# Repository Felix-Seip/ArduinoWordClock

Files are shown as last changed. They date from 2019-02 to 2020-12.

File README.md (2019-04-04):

# ArduinoWordClock
A code repository for an arduino word clock

This project was inspired by the QlockTwo word clock, which is uses the same basic code logic.
Currently, the only language that is supported with this repository is German. 
This is due to the layout of the LED matrix and the hardcoded position of the LEDs in the code.

However, this code can be used a basis of any word clock with an 11 x 11 LED matrix.

The main file for this clock is the .ino file, which is the main file that runs on the Arduino.
The other files, define a class that represent a word on the clock. 
These words include the words for the hours and minutes. 
The other words such as "vor" and "nach" are hard coded.

## Part List
This project uses a few different components in order to show the time in the LED matrix.
The following list is the part list required to recreate this word clock:
- 121 LEDs. The LEDs that should be used are LED strips. Each strip contains 11 LEDs. Since there are 11 rows, 121 LEDs are required
- DS1307 RTC. The RTC is used to control the LEDs and show the words on the clock
- DS18B20 Temperature Sensor. The sensor is used to display the temperature of the room that the clock is in
- GL5528 Photoresistor. The photoresistor is used to set the brightness of the LEDs depending on how bright it is in the room
- 1 x 10k Ohm Resistor
- 1 x 4.7k Ohm Resistor
- Arduino UNO or any other microcontroller with an ATMega328P chip
- HM-10 Bluetooth 4.0 Chip, available from DSD Tech on amazon.de

## LED Matrix Layout
The LED matrix that is used in this project is an 11 x 11 matrix. 
The LEDs are set up as follows:
11 LED strips. Each strip is one row for the matrix. 
Each LED strip contains 11 LEDs, thus the LED matrix is an 11 x 11.

The main entry point for the data and the power must be at the bottom left of the LED matrix. The data and power then travel from left to right, until reaching the last LED on the first strip. The next row is connected to the end of the first rows power, ground, and data pin, meaning that the second rows flow is from right to left. This continues all the way to the top where the last LED is at the top right of the LED matrix.

The layout looks like follows:
<br/>
<br/>
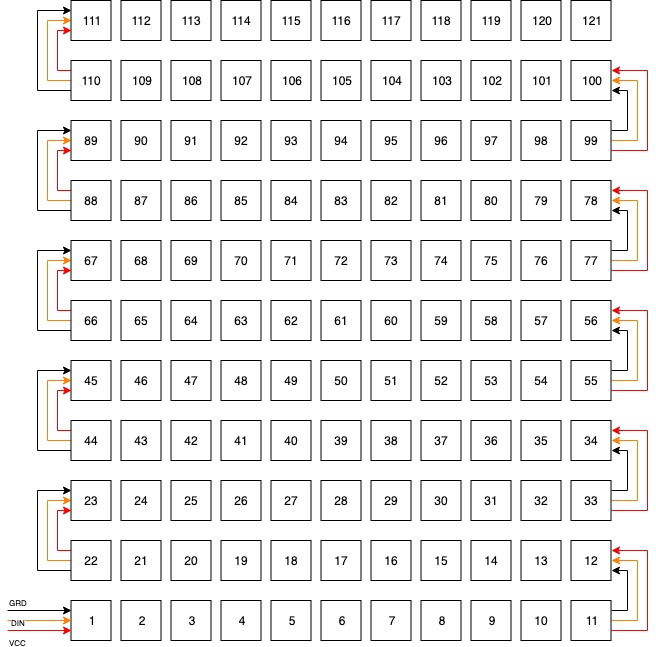
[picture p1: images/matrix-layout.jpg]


## Setting Up the Wiring 
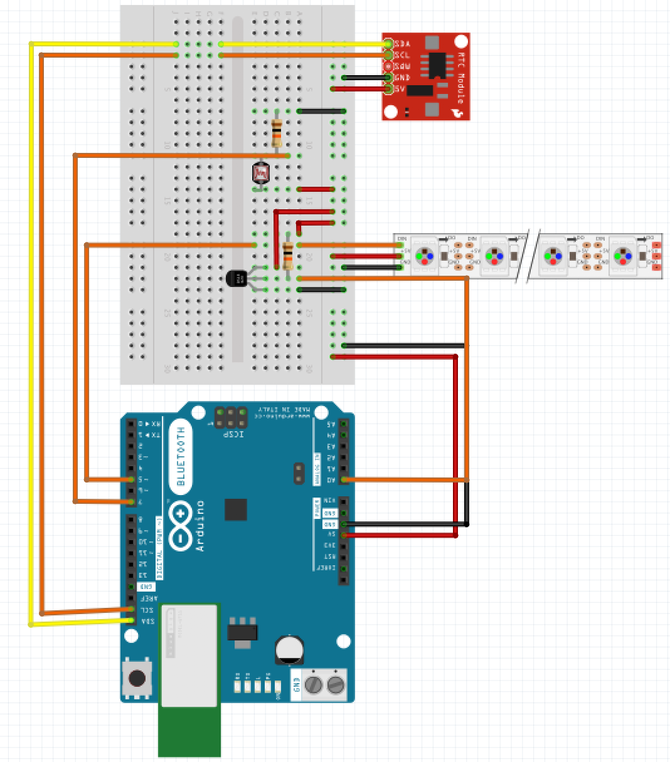
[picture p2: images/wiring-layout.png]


The above image shows the way to set up the wiring for the electronic components of this clock. The DS1307 is connected to the Arduinos SDA and SCL pins, while also being powered through the 5v and ground pin on the Arduino. The LEDs are controlled using the Arduinos pin 5 and also connect to the 5v and ground pins.

## ClockElement class
The ClockElement class describes a numerical word on the clock. It contains the definition for the range of LEDs that need to be lit up to display the full word, the element type, either HOUR or MINUTE, and the numerical values that it represents it. The class is very minimal and covers the necessary words to describe the time. 

## How do I Get This Code Up and Running on My Own Word Clock?
After setting up the electronics for your word clock, as described above, all you have to do is clone this repository and open it in the Arduino IDE. Choose the board that you are using through the tools menu and select the correct USB port. After doing this, you can upload the code, like uploading every other code, by simply pressing the upload button. 

## Required Additional Libraries
This code uses a few etxernal libraries that made interfacing with the hardware easier. The following libraries need to be downloaded and placed into the Arduino IDEs library folder:
- https://github.com/PaulStoffregen/Time
- https://www.arduinolibraries.info/libraries/vector
- https://www.arduinolibraries.info/libraries/ds1307-rtc
- https://www.arduinolibraries.info/libraries/dallas-temperature
- https://www.arduinolibraries.info/libraries/one-wire

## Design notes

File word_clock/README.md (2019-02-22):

# word_clock

A new Flutter project.

## Getting Started

This project is a starting point for a Flutter application.

A few resources to get you started if this is your first Flutter project:

- [Lab: Write your first Flutter app](https://flutter.io/docs/get-started/codelab)
- [Cookbook: Useful Flutter samples](https://flutter.io/docs/cookbook)

For help getting started with Flutter, view our 
[online documentation](https://flutter.io/docs), which offers tutorials, 
samples, guidance on mobile development, and a full API reference.

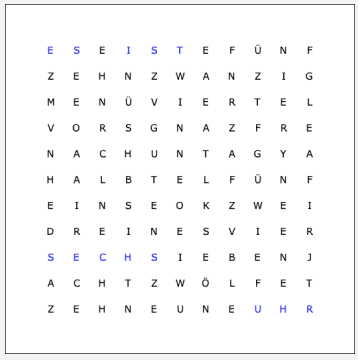
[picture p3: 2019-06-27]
word_clock/assets/word-clock.png

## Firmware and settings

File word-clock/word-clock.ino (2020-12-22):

#include <OneWire.h>
#include <Wire.h>
#include <FastLED.h>
#include <NTPClient.h>
#include <WiFiUdp.h>
#include <ESP8266WiFi.h>
#include <aREST.h>

#include "ClockElement.h"

//#define FASTLED_ESP8266_RAW_PIN_ORDER
#define NUM_LEDS 125
#define HEART_LEDS 10
#define NUM_CLOCK_ELEMENTS 19

#define DATA_PIN 5
#define pResistor A5
#define ONE_WIRE_BUS 7

aREST rest = aREST();
CRGB leds[NUM_LEDS];

IPAddress ip(192, 168, 2, 177);

/****************************************************
*****************CONFIGURE WIFI HERE*****************
*****************************************************/
char ssid[32] = "Seip"; 
char pass[32] = "connect.me"; 

IPAddress gateway(192, 168, 2, 1);
IPAddress subnet(255, 255, 255, 0);

long utcOffsetInSeconds = 7200;
boolean isConnectedToWifi = false;

WiFiUDP ntpUDP;
WiFiClient client;
WiFiServer server(80);
NTPClient timeClient(ntpUDP, "pool.ntp.org", utcOffsetInSeconds);

ClockElement timeClockElements[NUM_CLOCK_ELEMENTS];

//   Eins, Zwei, Drei, Vier, Fünf, Sechs, Sieben, Acht, Neun, Zehn, Elf, Zwölf, Null, Fünf, Zehn, Viertel, Zwanzig, Halb
int timeClockElementRangeFrom[NUM_CLOCK_ELEMENTS] = { 44,    51,   40,   33,   55,   22,    26,     18,   3,    0,    58,  13,  -1,   117,  106,  92,      99,      62  };
int timeClockElementRangeTo[NUM_CLOCK_ELEMENTS]   = { 48,    55,   44,   37,   59,   27,    32,     22,   7,    4,    61,  18,  -1,   121,  110,  99,      106,     66  };
int heartLEDs[HEART_LEDS] = {38, 48, 62, 69, 83, 71, 81, 73, 58, 50 };

struct CURRENT_TIME {
  int hours;
  int minutes;

  CURRENT_TIME(int h, int m) {
    hours = h;
    minutes = m;
  }
};


bool createdClockElements = false;
void createClockElements()
{
  createdClockElements = true;
  int clockElementIndex = 0;
  for (int i = 1; i <= 12; i++)
  {
    int numericValueAM = i;
    int numericValuePM = i + 12;

    if (i + 12 == 24)
    {
      numericValuePM = 0;
    }

    timeClockElements[clockElementIndex] = ClockElement(numericValueAM, numericValuePM, timeClockElementRangeFrom[i - 1], timeClockElementRangeTo[i - 1], HOUR);
    clockElementIndex++;
  }

  //Create the ClockElements for the minutes
  int minuteDistance = 60;
  int rangeIndex = 12;
  for (int i = 0; i <= 30; i += 5)
  {
    int numericValueAM = i;
    int numericValuePM = i + minuteDistance;

    if (i == 30) {
      rangeIndex--;
    }

    timeClockElements[clockElementIndex] = ClockElement(numericValueAM, numericValuePM, timeClockElementRangeFrom[rangeIndex], timeClockElementRangeTo[rangeIndex], MINUTE);

    rangeIndex++;
    minuteDistance -= 10;
    clockElementIndex++;
  }
}


void setup()
{
  Serial.begin(9600);

  // Function to be exposed
  rest.function("clockcolor", setPixelColor);
  rest.function("clockconfiguration", configureClock);

  rest.function("wordclockfreya", showFreya);
  rest.function("setDST", setDST);

  //Opposite of beginAP is WiFi.begin
  WiFi.config(ip, gateway, subnet);
  WiFi.begin(ssid, pass);
  while ( WiFi.status() != WL_CONNECTED ) {
    delay ( 500 );
    Serial.print ( "." );
  }

  
  Serial.println(WiFi.localIP());

  server.begin();
  // you're connected now, so print out the status:
  createClockElements();
  FastLED.addLeds<WS2812B, DATA_PIN>(leds, NUM_LEDS);

  timeClient.begin();
}

char color[3] = {255, 255, 255};

bool showUhrWord = true;
void loop()
{

  String clientRequest = "";

  client = server.available();   // listen for incoming clients

  while (client.connected()) {
    rest.handle(client);
    handleClockFunctions();
  }

  handleClockFunctions();
  delay(100);
}

int setDST(String dst) {
  utcOffsetInSeconds = dst.toInt();  
  return 1;
}

int configureClock(String configuration) {
  Serial.println("Configuring clock with following parameters:");
  String wifiSSID = "";
  String wifiPassword = "";
  String clockRoomName = "";

  int beginningIndex = 0;
  int configIndex = 0;
  String wifiConfiguration[3];
  while (configuration.indexOf(",", beginningIndex) != -1) {
    int index = configuration.indexOf(",", beginningIndex);
    wifiConfiguration[configIndex] = configuration.substring(beginningIndex, index);
    beginningIndex = index + 1;
    configIndex++;
  }

  wifiConfiguration[configIndex] = configuration.substring(beginningIndex, configuration.length());

  for (int i = 0; i < 3; i++) {
    String wifiConfig = wifiConfiguration[i];
    String configKeyValue[2];
    configKeyValue[0] = wifiConfig.substring(0, wifiConfig.indexOf("=", 0));
    configKeyValue[1] = wifiConfig.substring(configKeyValue[0].length() + 1, wifiConfig.length());

    Serial.print(configKeyValue[0] + ": ");
    Serial.println(configKeyValue[1]);

    if (i == 0) {
      Serial.println(configKeyValue[0]);
      configKeyValue[0].toCharArray(ssid, configKeyValue[0].length() + 1);
      Serial.println(ssid);
    } else if (configKeyValue[0].equals("password")) {
      configKeyValue[1].toCharArray(pass, configKeyValue[1].length() + 1);
    } 
  }

  return 1;
}

void handleClockFunctions() {

    CURRENT_TIME currentTime = getTimeFromNTPServer();

    resetAllLEDs();
    showBasicClockElements();
    showMinuteLEDs(currentTime.minutes, currentTime.hours, showUhrWord);
    showHourLEDs(currentTime.hours);

    if (showUhrWord)
    {
      //Light up the LEDs for the word "UHR"
      leds[8] = CRGB(color[1], color[0], color[2]);
      leds[9] = CRGB(color[1], color[0], color[2]);
      leds[10] = CRGB(color[1], color[0], color[2]);
    }

  FastLED.show();
}

CURRENT_TIME getTimeFromNTPServer() {
  timeClient.update();
  delay(1000);
  return CURRENT_TIME(timeClient.getHours(), timeClient.getMinutes());
}

int showFreya(String command) {
  showWordFreya();
}

//http://192.168.4.1/rgb?param=1,2,3
int setPixelColor(String rgb) {
  int beginningIndex = 0;
  int colorIndex = 0;
  while (rgb.indexOf(",", beginningIndex) != -1) {
    int index = rgb.indexOf(",", beginningIndex);
    Serial.println(rgb.substring(beginningIndex, index));
    color[colorIndex] = rgb.substring(beginningIndex, index).toInt();
    beginningIndex = index + 1;
    colorIndex++;
  }
  color[colorIndex] = rgb.substring(beginningIndex, rgb.length()).toInt();

  FastLED.show();
  // set single pixel color
  return 1;
}

void showHourLEDs(int &hours) {
  Serial.print("Hour to show: ");
  Serial.println(hours);

  ClockElement clockElement = findClockElementByNumericValueAndType(hours, HOUR);

  Serial.print("Hour that will be shown: ");
  Serial.println(clockElement.GetNumericValuePM());
  Serial.println("");

  setColorForClockElement(clockElement, color[1], color[0], color[2]);
}

void showMinuteLEDs(int minutes, int &hours, bool &showUhrWord) {
  if (minutes >= 0 && minutes < 5) {
    showUhrWord = true;
  }
  else {
    showUhrWord = false;
  }

  if (minutes != 0) {
    if ((minutes >= 25 && minutes < 30) || (minutes >= 35 && minutes < 40))
    {
      ClockElement element = findClockElementByNumericValueAndType(5, MINUTE);
      setColorForClockElement(element, color[0], color[1], color[2]);

      if (minutes >= 25 && minutes < 30)
      {
        showWordVor();
      }
      else if (minutes >= 35 && minutes < 40)
      {
        showWordNach();
      }
    }

    if (60 - minutes > 35 && !(minutes >= 0 && minutes < 5))
    {
      showWordNach();
    }
    else if (60 - minutes < 25 && !(minutes >= 0 && minutes < 5))
    {
      showWordVor();
    }

    if (60 - minutes < 25 || (minutes >= 25 && minutes < 30) ||
        (minutes >= 35 && minutes < 40) || (minutes >= 30 && minutes < 35)) {
      hours = hours + 1;
    }
    showLeftOverMinuteLEDs(minutes % 5);
  }

  ClockElement clockElement = findClockElementByNumericValueAndType(minutes - (minutes % 5), MINUTE);
  setColorForClockElement(clockElement, color[1], color[0], color[2]);
}

void showLeftOverMinuteLEDs(int leftOverMinutes) {
  for (int i = 124; i > 124 - leftOverMinutes; i--) {
    leds[i] = CRGB(color[1], color[0], color[2]);
  }
}

void resetAllLEDs() {
  //Reset time words
  for (int i = 0; i < NUM_LEDS; i++) {
    leds[i] = CRGB(0, 0, 0);
  }
}

void showBasicClockElements() {
  //Light up the LEDs for the word "ES"
  leds[110] = CRGB(color[1], color[0], color[2]);
  leds[111] = CRGB(color[1], color[0], color[2]);

  //Light up the LEDs for the word "IST"
  leds[113] = CRGB(color[1], color[0], color[2]);
  leds[114] = CRGB(color[1], color[0], color[2]);
  leds[115] = CRGB(color[1], color[0], color[2]);
}

void showWordVor() {
  //Light up the LEDs for the word "VOR"
  leds[85] = CRGB(color[1], color[0], color[2]);
  leds[86] = CRGB(color[1], color[0], color[2]);
  leds[87] = CRGB(color[1], color[0], color[2]);
}

void showWordNach() {
  //Light up the LEDs for the word "NACH"
  leds[66] = CRGB(color[1], color[0], color[2]);
  leds[67] = CRGB(color[1], color[0], color[2]);
  leds[68] = CRGB(color[1], color[0], color[2]);
  leds[69] = CRGB(color[1], color[0], color[2]);
}

void showWordFreya() {
  showUhrWord = false;
  //Light up the LEDs for the word "FREYA"
  leds[75] = CRGB(0, 255, 0);
  leds[76] = CRGB(0, 255, 0);
  leds[77] = CRGB(0, 255, 0);
  leds[78] = CRGB(0, 255, 0);
  leds[79] = CRGB(0, 255, 0);

  for (int i = 0; i < HEART_LEDS; i++) {
    leds[heartLEDs[i]] = CRGB(0, 255, 0);
    FastLED.delay(150);
  }
  delay(150);

  for (int i = 0; i < HEART_LEDS; i++) {
    leds[heartLEDs[i]] = CRGB(0, 0, 0);
    FastLED.delay(150);
  }
  showUhrWord = true;
}

void setColorForClockElement(ClockElement clockElement, int r, int g, int b) {
  for (int k = clockElement.GetRangeFrom(); k < clockElement.GetRangeTo(); k++)
  {
    leds[k] = CRGB(r, g, b);
  }
}

ClockElement findClockElementByNumericValueAndType(int numericValue, CLOCK_ELEMENT_TYPE elementType) {
  ClockElement *foundElement = NULL;

  for (int i = 0; i < NUM_CLOCK_ELEMENTS; i++)
  {
    ClockElement clockElement = timeClockElements[i];

    if (elementType == MINUTE && clockElement.GetClockElementType() == MINUTE) {
      if ((numericValue == clockElement.GetNumericValueAM() || numericValue == clockElement.GetNumericValuePM())) {
        return timeClockElements[i];
      }
    } else if (elementType == HOUR && clockElement.GetClockElementType() == HOUR) {
      if (numericValue == clockElement.GetNumericValueAM() || numericValue == clockElement.GetNumericValuePM()) {
        return timeClockElements[i];
      }

    }
  }

  if (foundElement == NULL) {
    Serial.print("foundElement of type ");
    if (elementType == HOUR) {
      Serial.println("hour is NULL");
    } else if (elementType == MINUTE) {
      Serial.println("minute is NULL");
    }
  }

  return *foundElement;
}

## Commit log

2019-02-11 Added fritzing file for the electronics layout
    [arduino-wiring.fzz]
2019-02-11 Added image of the wiring layout for the readme
2019-02-22 Added project for the mobile app
    [arduino-wiring.fzz]
2019-02-24 Added functionality for the temperature reading and the birghtness. Also added code for the word clock app
2019-02-25 Added new components to the Fritzing drawing. Also added code for handling the temperature display and the brightness of the LEDs
    [arduino-wiring.fzz]
2019-02-25 Update README.md
    Added links for the new libraries and added description that the DS18B20 and GL5528 sensors are required
2019-03-17 Added functionality to change the color of the LEDs from the app. Also added error handling when bluetooth is not available
    [word-clock.ino]
2019-04-04 Changed color picker dialog. Fixed minute display. Updated icon for app
    [word-clock.ino]
2019-06-13 Added new animation functionality, developed by y@nnicky@nnickwolf.de
2019-06-27 Changed clock functionality to WiFi since bluetooth wasn't working out too well. Added discovery in the app which shows a list of available devices in the local network. Clock currently not working, 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
    [word-clock.ino]
2019-06-27 Fixed bug where microcontroller wasn't responding. Was caused due to a memory issue on the MKR1010 using the Vector library. Changed to a simple array of objects
    [word-clock.ino]
2019-06-27 Fixed clock commands. Also fixed color not changing to configured color
    [word-clock.ino]
2019-06-28 Fixed blocking NTP calls
    [word-clock.ino]
2019-07-08 Disabled getting time from internet, since it is still broken. Added a setup mode that is shown when the device is first connected. Correct display of the time is also broken
    [word-clock.ino]
2019-07-17 Changed refresh indicator to stay until scanning for devices has completed
2020-01-24 Minor fixes to the functionality of the word clock
    [word-clock.ino]
2020-04-19 Fixed time UTC offset to +2
    [word-clock.ino]
2020-04-26 Default LEDs shown when clock is not connected to wifi
2020-04-26 Fixed word clock configuration
    [word-clock.ino]
